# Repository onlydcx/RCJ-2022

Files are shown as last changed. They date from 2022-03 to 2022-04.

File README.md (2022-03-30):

# このプロジェクトについて
ロボカップジュニア2022に出場する機体の全データです。要はオープンソースです。

需要があるかは分かりませんが、公開すること自体が大事だと思うので公開します

# 3Dデータ
3Dデータ フォルダに入ってます。

Autodesk Fusion360で作成しました、f3zファイルなのでFusionでしか開けないと思います。

# ソフトウェア
PlatfomIOで開発しています。

必要なplatformio.iniとmain.cppだけ載せておきます。

質問とかあったらTwitterでDMしてください

# 基板データ
基板データ フォルダに入ってます。
- 「CamBoard」 メイン基板のデータです。OpenMV,Teensyなどが乗ります
- 「FrontLine」 前のLINEセンサーのデータです。ボール補足エリアがあるので前だけラインセンサの形が違います。
- 「Kicker」 キッカー用のMOSFETが乗った回路です。コンデンサは別付けです。
- 「PowerUnit」 リポから5V,3.3Vを生成してメイン基板に送る回路です。ヒューズも乗ります。
- 「SideLine」 横と後ろのラインセンサーのデータです
- 「UI-unit」 UI基盤のデータです。0.96inchのOLEDが乗ります

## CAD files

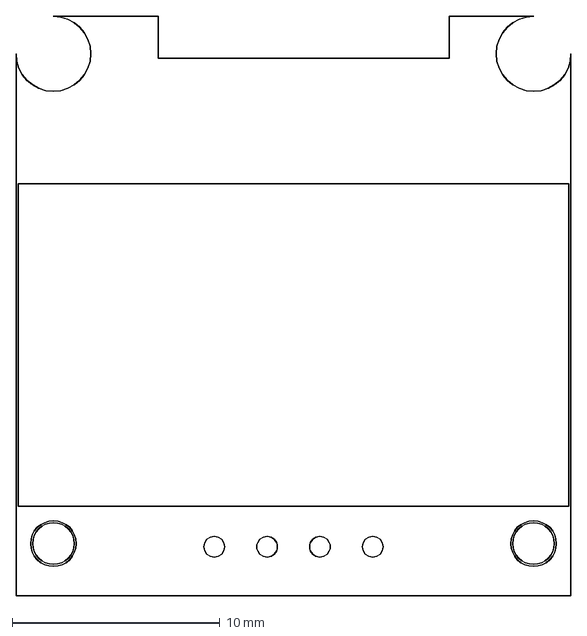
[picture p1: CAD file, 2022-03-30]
基板データ/CamBoard/OLED-Edge.dxf
26.7 x 27.9 mm

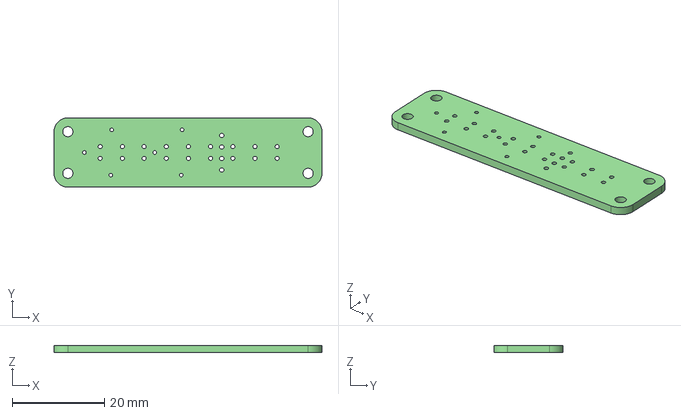
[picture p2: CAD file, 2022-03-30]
基板データ/FrontLine/FrontLine.step
58.0 x 15.0 x 1.60 mm

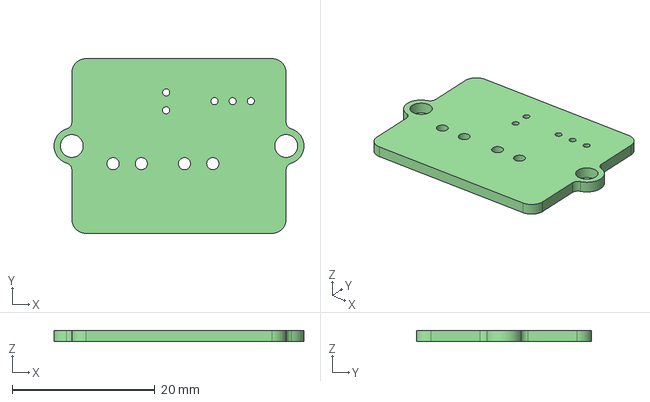
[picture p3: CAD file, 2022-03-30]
基板データ/Kicker/Kicker.step
35.0 x 24.5 x 1.60 mm

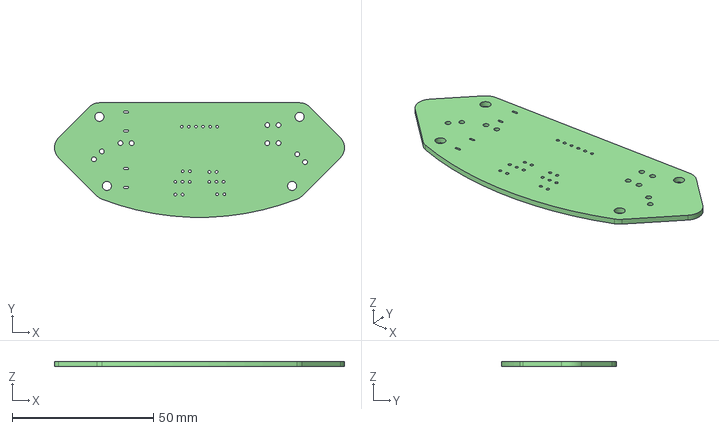
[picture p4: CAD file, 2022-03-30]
基板データ/PowerUnit/PowerUnit.step
102.7 x 40.5 x 1.60 mm

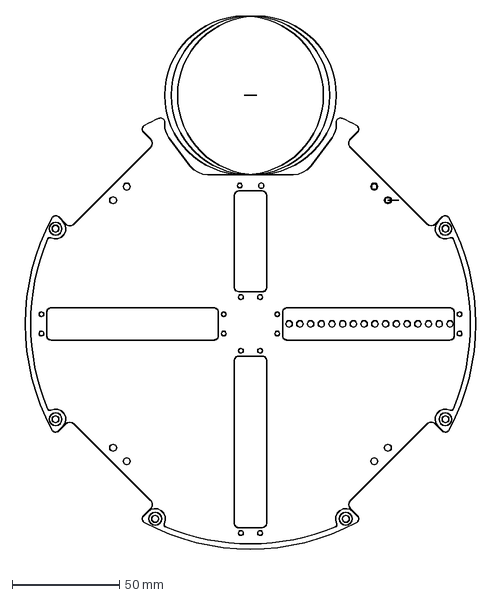
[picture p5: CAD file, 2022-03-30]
基板データ/SideLine/Edge.dxf
218.2 x 252.7 mm

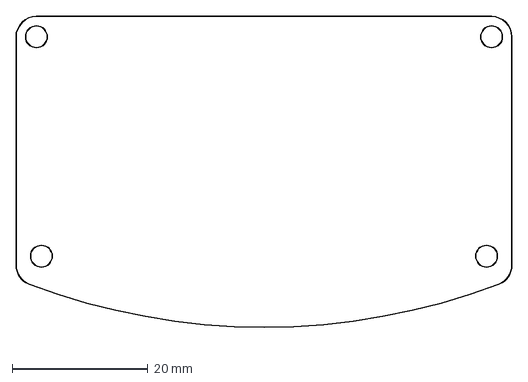
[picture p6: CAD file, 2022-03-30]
基板データ/UI-unit/Edge.dxf
73.0 x 47.9 mm

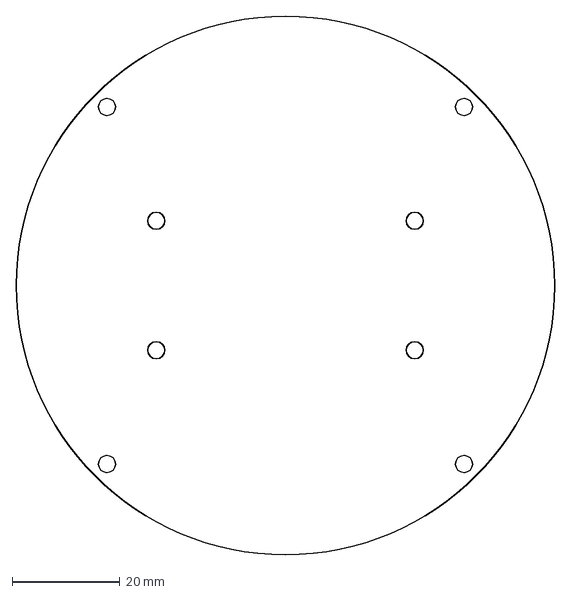
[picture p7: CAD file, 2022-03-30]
基板データ/CamBoard/Edge.dxf
100.0 x 100.0 mm

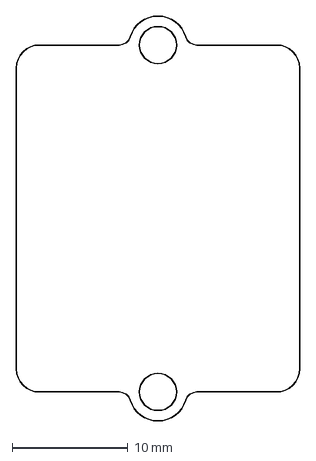
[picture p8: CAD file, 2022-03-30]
基板データ/Kicker/Edge.dxf
24.5 x 35.0 mm

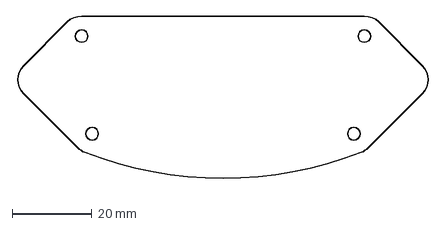
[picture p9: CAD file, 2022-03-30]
基板データ/PowerUnit/Edge.dxf
103.7 x 42.8 mm

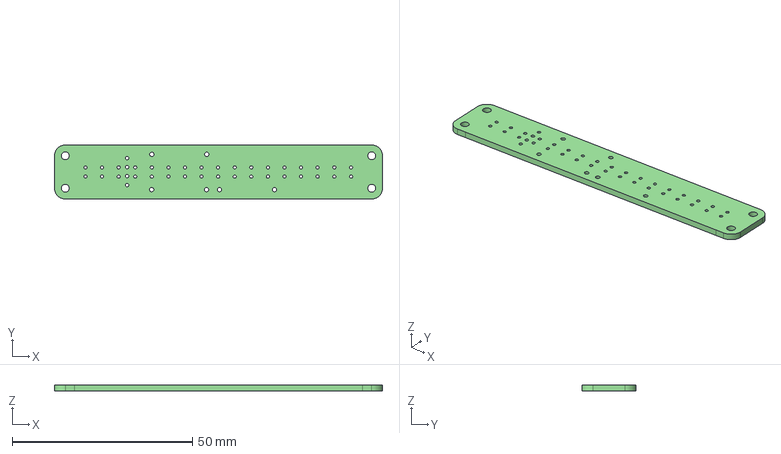
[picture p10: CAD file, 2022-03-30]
基板データ/SideLine/SideLine.step
91.0 x 15.0 x 1.60 mm

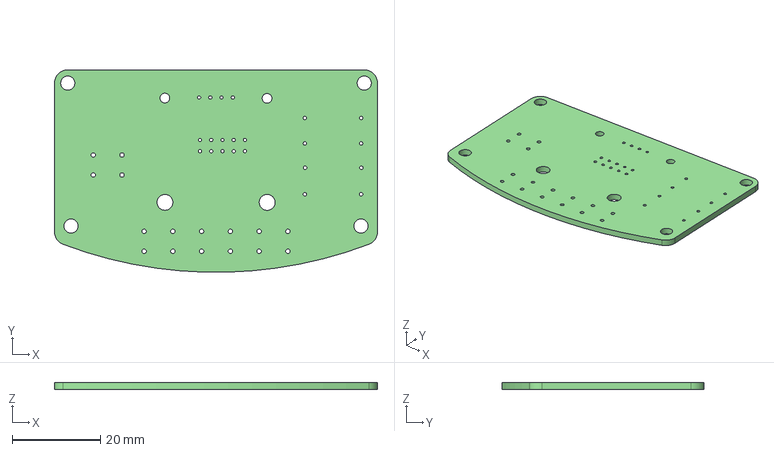
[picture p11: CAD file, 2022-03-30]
基板データ/UI-unit/UI-unit.step
73.0 x 45.7 x 1.60 mm

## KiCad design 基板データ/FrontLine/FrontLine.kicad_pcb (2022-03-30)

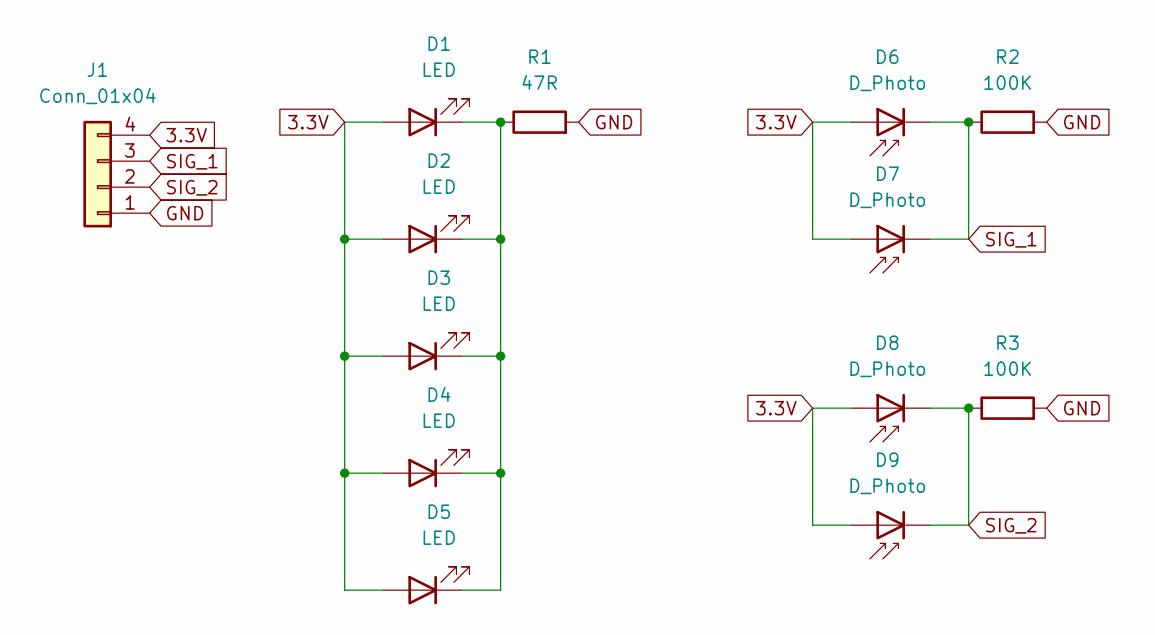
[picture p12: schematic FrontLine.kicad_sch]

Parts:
D1, D2, D3, D4, D5: LED; LED_D3.0mm
D6, D7, D8, D9: D_Photo; NJL7302L_F3
J1: Conn_01x04; JST_XH_S4B-XH-A-1_1x04_P2.50mm_Horizontal
R1: 47R; R_Axial_DIN0309_L9.0mm_D3.2mm_P15.24mm_Horizontal
R2, R3: 100K; R_Axial_DIN0309_L9.0mm_D3.2mm_P15.24mm_Horizontal

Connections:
3.3V: D1.2 (A), D2.2 (A), D3.2 (A), D4.2 (A), D5.2 (A), D6.2 (A), D7.2 (A), D8.2 (A), D9.2 (A), J1.4
GND: J1.1, R1.2, R2.2, R3.2
unnamed: D1.1 (K), D2.1 (K), D3.1 (K), D4.1 (K), D5.1 (K), R1.1
SIG_1: D6.1 (K), D7.1 (K), J1.3, R2.1
SIG_2: D8.1 (K), D9.1 (K), J1.2, R3.1

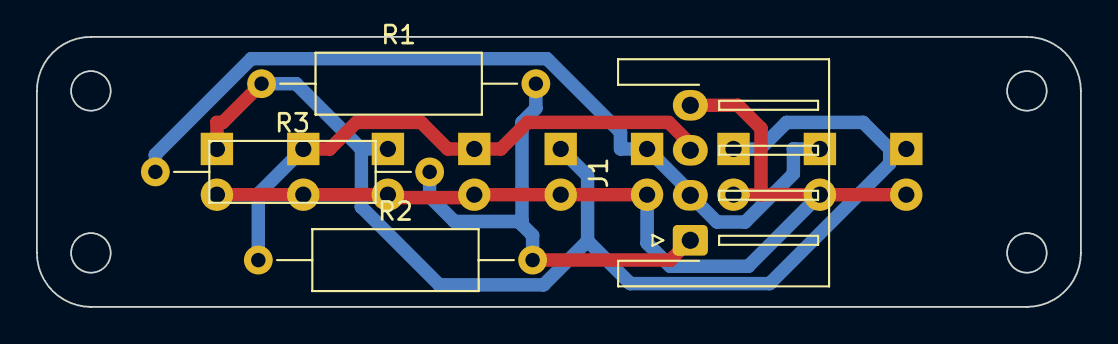
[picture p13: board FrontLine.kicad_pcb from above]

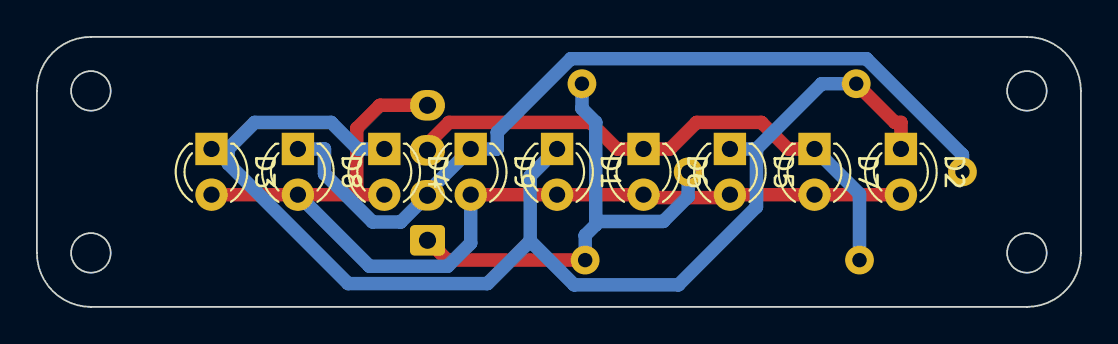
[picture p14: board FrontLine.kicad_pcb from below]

Board: 2 copper layers, 58.0 x 15.0 mm, 13 parts (9 on the bottom side), 5 nets.

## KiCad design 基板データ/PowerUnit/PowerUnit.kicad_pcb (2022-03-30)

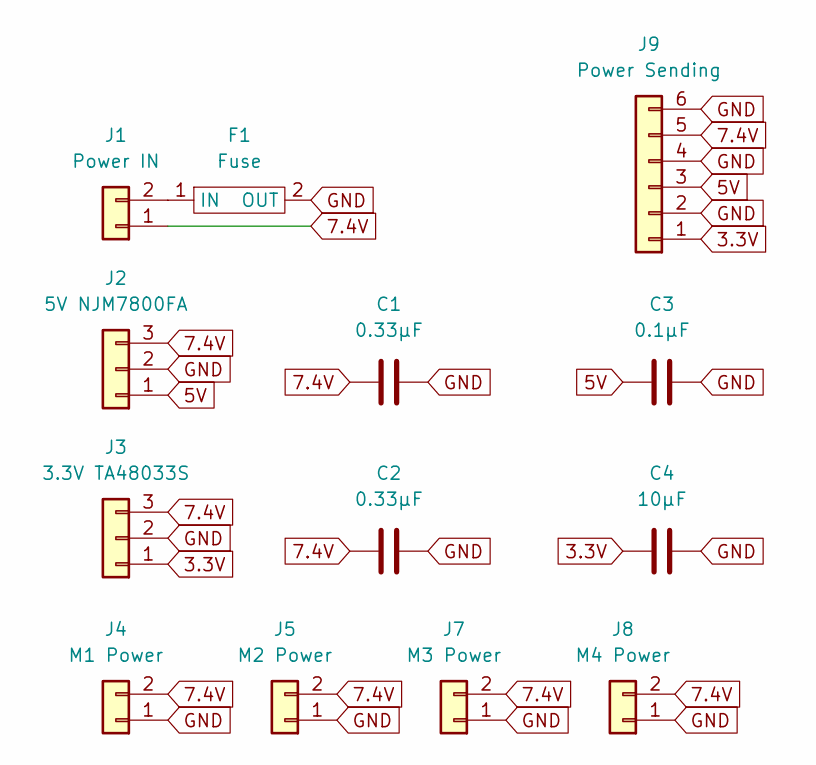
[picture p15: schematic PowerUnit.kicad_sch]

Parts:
C1: 0.33μF; PinSocket_1x02_P2.54mm_Vertical
C2: 0.33µF; PinSocket_1x02_P2.54mm_Vertical
C3: 0.1μF; PinSocket_1x02_P2.54mm_Vertical
C4: 10µF; PinSocket_1x02_P2.54mm_Vertical
F1: Fuse
J1: Power IN; JST_VH_S2P-VH_1x02_P3.96mm_Horizontal
J2: 5V NJM7800FA; PinSocket_1x03_P2.54mm_Horizontal
J3: 3.3V TA48033S; PinSocket_1x03_P2.54mm_Horizontal
J4: M1 Power; JST_VH_S2P-VH_1x02_P3.96mm_Horizontal
J5: M2 Power; JST_VH_S2P-VH_1x02_P3.96mm_Horizontal
J7: M3 Power; JST_VH_S2P-VH_1x02_P3.96mm_Horizontal
J8: M4 Power; JST_VH_S2P-VH_1x02_P3.96mm_Horizontal
J9: Power Sending; JST_XH_S6B-XH-A-1_1x06_P2.50mm_Horizontal

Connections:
3.3V: C4.2, J3.1, J9.1
5V: C3.2, J2.1, J9.3
7.4V: C1.2, C2.2, J1.1, J2.3, J3.3, J4.2, J5.2, J7.2, J8.2, J9.5
GND: C1.1, C2.1, C3.1, C4.1, F1.2 (OUT), J2.2, J3.2, J4.1, J5.1, J7.1, J8.1, J9.2, J9.4, J9.6
unnamed: F1.1 (IN), J1.2

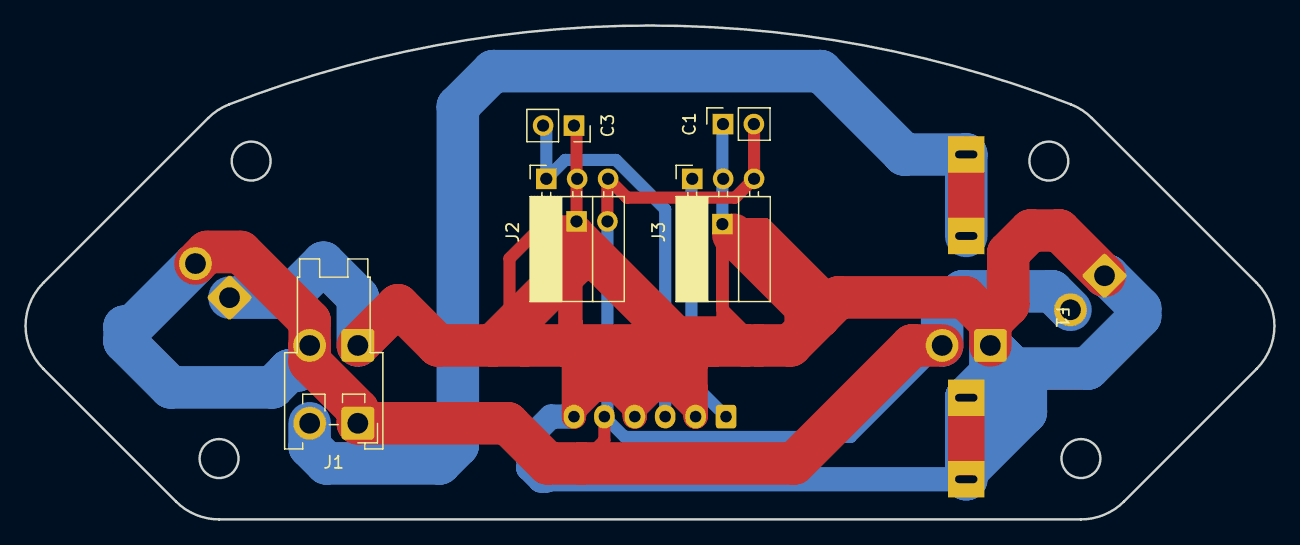
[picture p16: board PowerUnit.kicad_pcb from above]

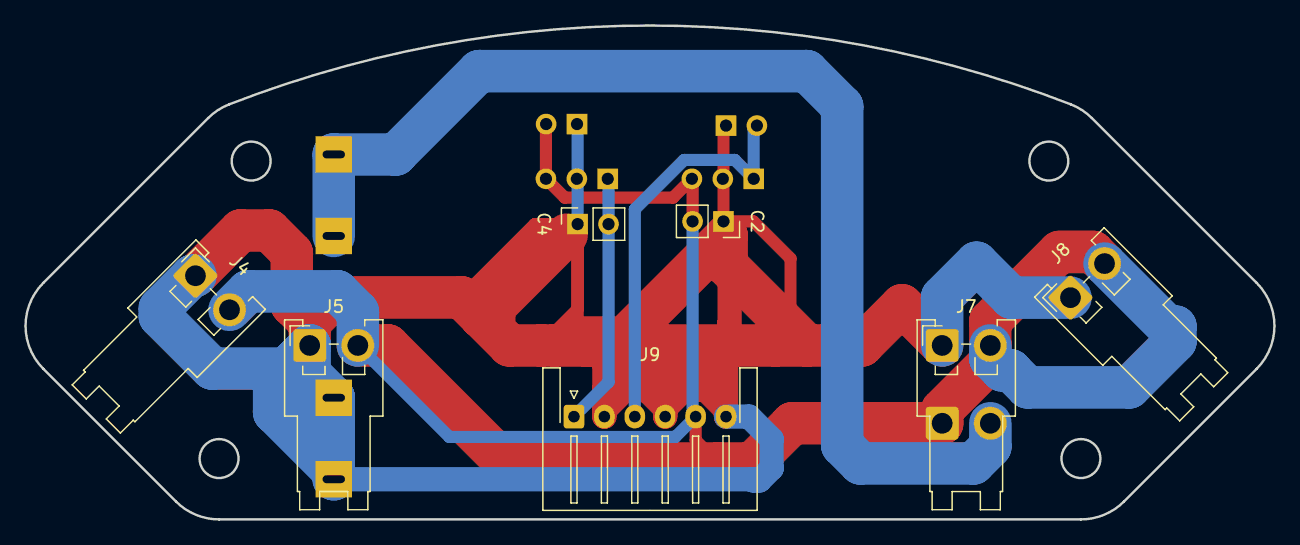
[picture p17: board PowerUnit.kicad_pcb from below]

Board: 2 copper layers, 102.7 x 40.6 mm, 13 parts (7 on the bottom side), 5 nets.

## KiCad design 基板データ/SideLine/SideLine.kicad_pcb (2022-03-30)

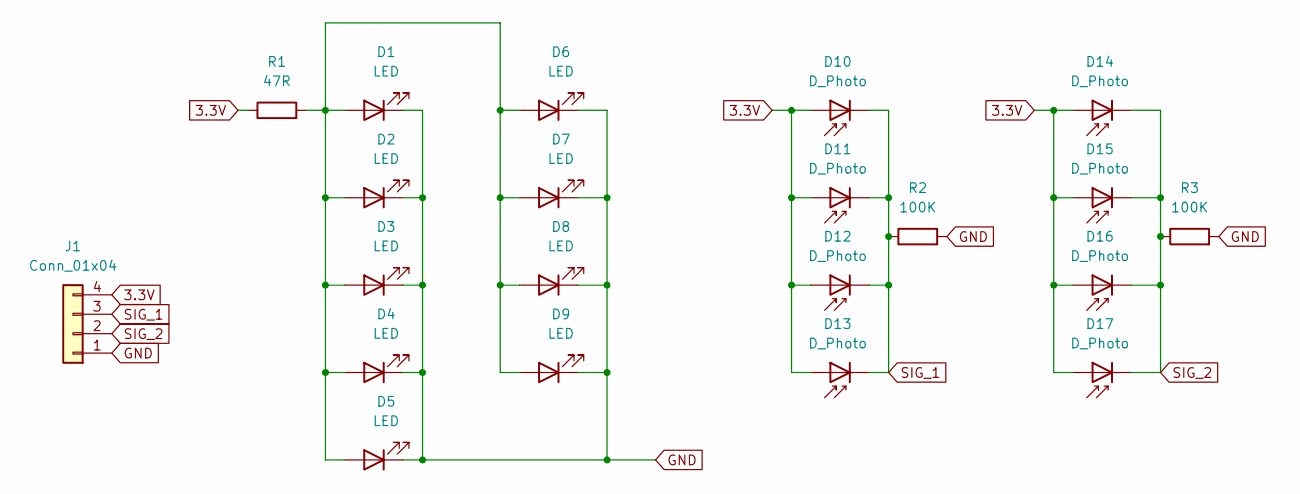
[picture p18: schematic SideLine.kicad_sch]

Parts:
D1, D2, D3, D4, D5, D6, D7, D8, D9: LED; LED_D3.0mm
D10, D11, D12, D13, D14, D15, D16, D17: D_Photo; NJL7302L_F3
J1: Conn_01x04; JST_XH_S4B-XH-A-1_1x04_P2.50mm_Horizontal
R1: 47R; R_Axial_DIN0411_L9.9mm_D3.6mm_P15.24mm_Horizontal
R2, R3: 100K; R_Axial_DIN0411_L9.9mm_D3.6mm_P15.24mm_Horizontal

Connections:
3.3V: D10.2 (A), D11.2 (A), D12.2 (A), D13.2 (A), D14.2 (A), D15.2 (A), D16.2 (A), D17.2 (A), J1.4, R1.1
GND: D1.1 (K), D2.1 (K), D3.1 (K), D4.1 (K), D5.1 (K), D6.1 (K), D7.1 (K), D8.1 (K), D9.1 (K), J1.1, R2.2, R3.2
unnamed: D1.2 (A), D2.2 (A), D3.2 (A), D4.2 (A), D5.2 (A), D6.2 (A), D7.2 (A), D8.2 (A), D9.2 (A), R1.2
SIG_1: D10.1 (K), D11.1 (K), D12.1 (K), D13.1 (K), J1.3, R2.1
SIG_2: D14.1 (K), D15.1 (K), D16.1 (K), D17.1 (K), J1.2, R3.1

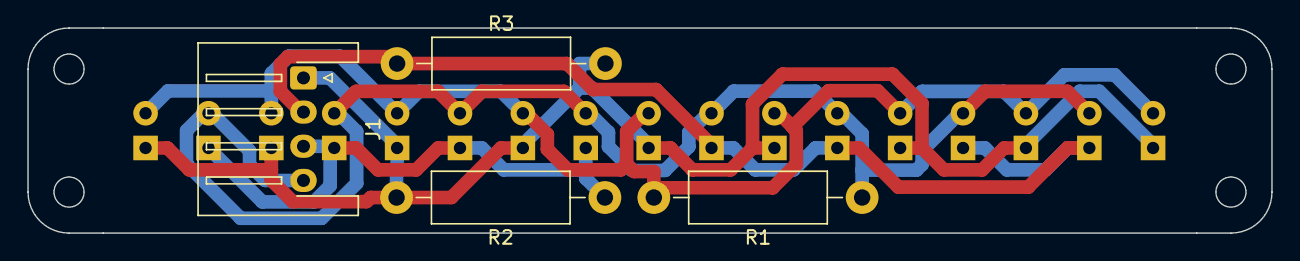
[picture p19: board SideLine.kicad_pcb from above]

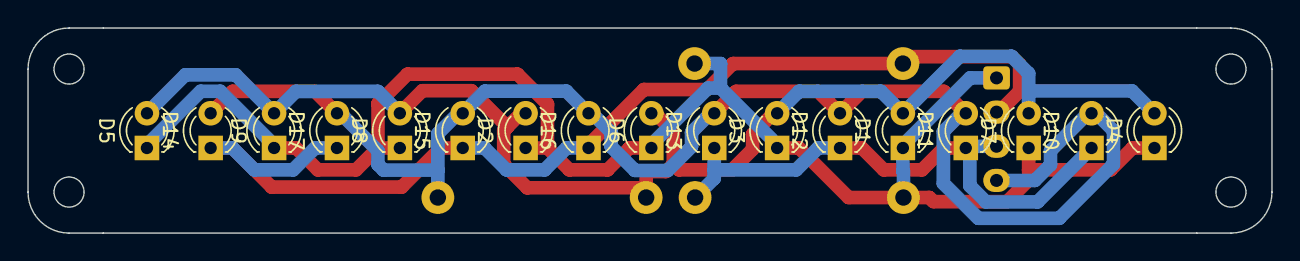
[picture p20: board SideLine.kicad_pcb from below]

Board: 2 copper layers, 91.0 x 15.0 mm, 21 parts (17 on the bottom side), 5 nets.

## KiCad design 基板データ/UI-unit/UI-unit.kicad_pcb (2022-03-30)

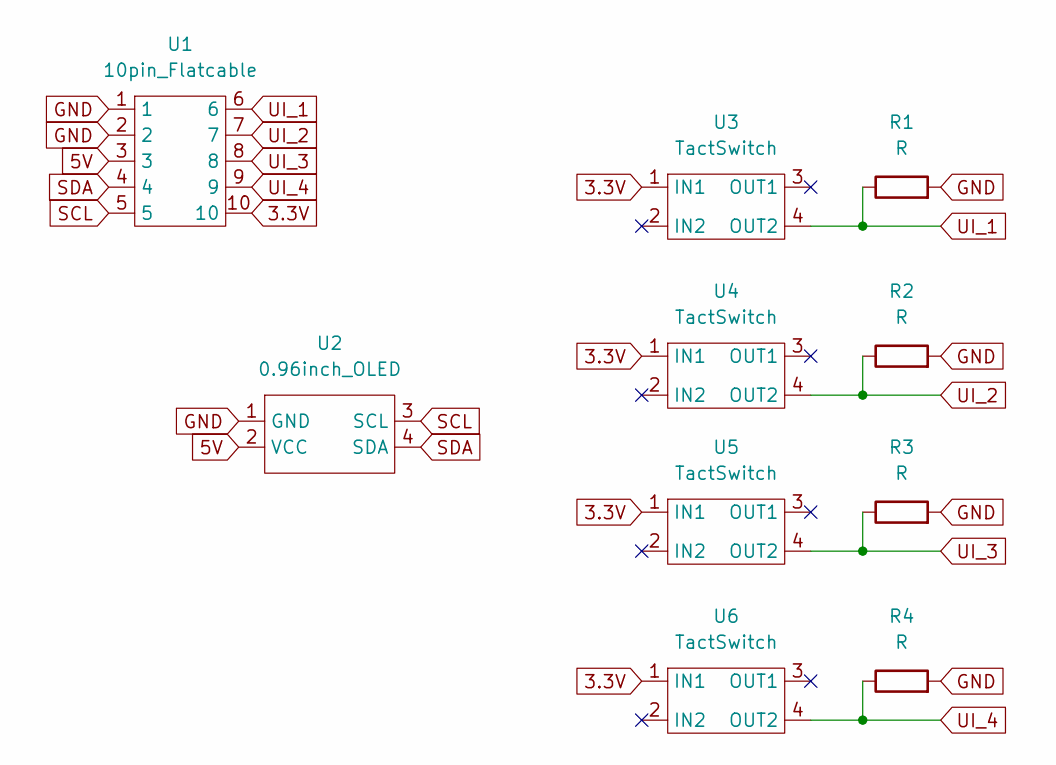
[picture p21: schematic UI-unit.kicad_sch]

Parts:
R1, R2, R3, R4: R; R_Axial_DIN0309_L9.0mm_D3.2mm_P12.70mm_Horizontal
U1: 10pin_Flatcable
U2: 0.96inch_OLED
U3, U4, U5, U6: TactSwitch

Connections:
3.3V: U1.10, U3.1 (IN1), U4.1 (IN1), U5.1 (IN1), U6.1 (IN1)
5V: U1.3, U2.2 (VCC)
GND: R1.2, R2.2, R3.2, R4.2, U1.1, U1.2, U2.1 (GND)
SCL: U1.5, U2.3 (SCL)
SDA: U1.4, U2.4 (SDA)
UI_1: R1.1, U1.6, U3.4 (OUT2)
UI_2: R2.1, U1.7, U4.4 (OUT2)
UI_3: R3.1, U1.8, U5.4 (OUT2)
UI_4: R4.1, U1.9, U6.4 (OUT2)

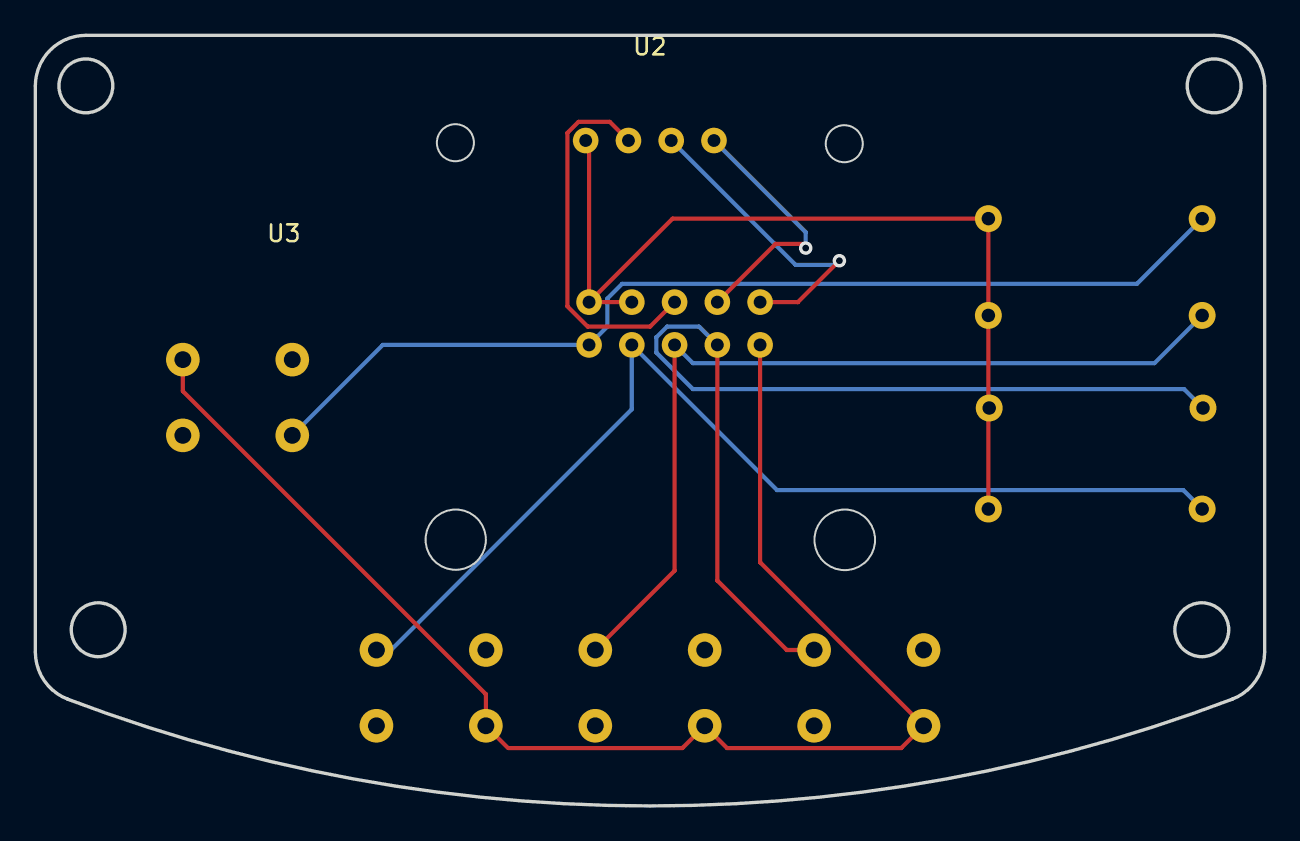
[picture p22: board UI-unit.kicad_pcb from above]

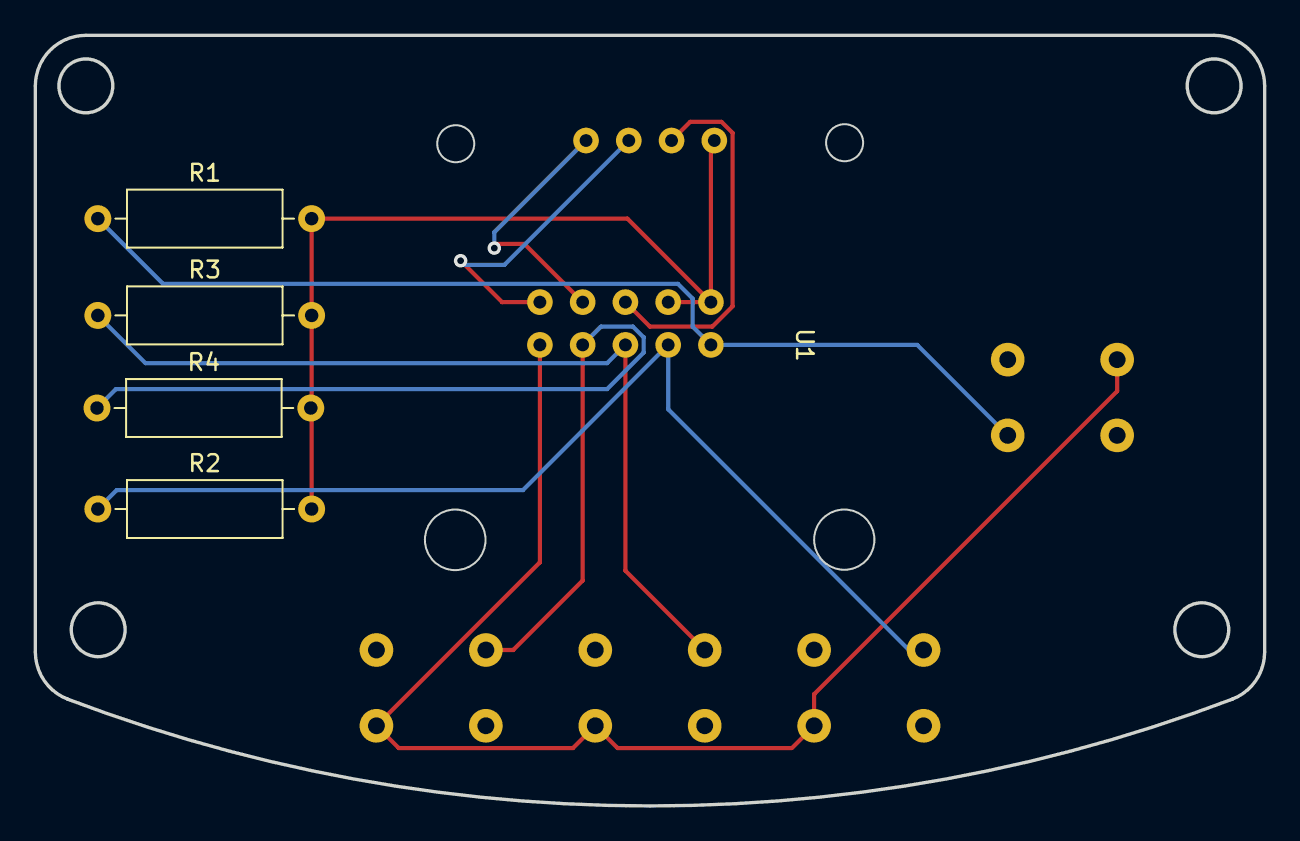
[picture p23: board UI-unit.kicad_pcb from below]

Board: 2 copper layers, 73.0 x 45.8 mm, 10 parts (5 on the bottom side), 9 nets.

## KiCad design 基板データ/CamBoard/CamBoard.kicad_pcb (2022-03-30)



Board: 2 copper layers, 100.0 x 100.0 mm, 28 parts (8 on the bottom side), 39 nets.

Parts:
C1: C; PinSocket_1x02_P2.54mm_Vertical
J1: Power IN; JST_XH_B6B-XH-A_1x06_P2.50mm_Vertical
J2: Voltage; JST_XH_B2B-XH-A_1x02_P2.50mm_Vertical
J3, J5: I2C Port; JST_XH_B4B-XH-A_1x04_P2.50mm_Vertical
J4: Gyro; PinSocket_1x08_P2.54mm_Vertical
J6, J7, J8, J9: HC SR04; PinSocket_1x04_P2.54mm_Vertical
J10: Motor Right; JST_XH_S8B-XH-A_1x08_P2.50mm_Horizontal
J11: Motor Left; JST_XH_S8B-XH-A_1x08_P2.50mm_Horizontal
J12: MotorSwitch; PinSocket_1x03_P2.54mm_Vertical
J13: LIne Right; JST_XH_S8B-XH-A_1x08_P2.50mm_Horizontal
J14: Line Left; JST_XH_S8B-XH-A_1x08_P2.50mm_Horizontal
J15: Conn_01x04; JST_XH_B4B-XH-A_1x04_P2.50mm_Vertical
R1, R2, R5, R6: R; R_Axial_DIN0309_L9.0mm_D3.2mm_P12.70mm_Horizontal
R3, R4: 100K; R_Axial_DIN0309_L9.0mm_D3.2mm_P12.70mm_Horizontal
R7, R9: 100k; R_Axial_DIN0309_L9.0mm_D3.2mm_P12.70mm_Horizontal
R8: 47; R_Axial_DIN0309_L9.0mm_D3.2mm_P12.70mm_Horizontal
U1: 10pin_FlatCable; 20pin_FlatCable
U2: OpenMV; OPENMV_H7
U3: Teensy4.0; Teensy40

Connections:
3.3V: J1.2, J12.3, J13.4, J13.8, J14.4, J14.8, J15.2, R8.2, U1.10
5V: C1.2, J1.4, J3.2, J4.8, J5.2, J6.4, J7.4, J8.4, J9.4, J10.4, J10.8, J11.4, J11.8, U1.3, U2.10, U3.33
7.4V: J1.6, J2.2
A0: J13.1, U3.21
A1: J13.2, U3.22
A2: J13.5, U3.23
A3: J13.6, U3.24
A6: J14.1, U3.27
A7: J14.2, U3.28
A8: J14.5, U3.29
A9: J14.6, U3.30
A12: J15.1, R9.2, U3.37
GND: C1.1, J1.1, J1.3, J1.5, J2.1, J3.1, J4.7, J5.1, J6.1, J7.1, J8.1, J9.1, J10.3, J10.7, J11.3, J11.7, J13.3, J13.7, J14.3, J14.7, J15.3, R3.1, R4.1, R7.1, R9.1, U1.1, U1.2, U2.9, U3.1, U3.17, U3.32
HC-SR04-Back: J8.3, R5.2
HC-SR04-Front: J6.3, R1.2
HC-SR04-Left: J7.3, R2.2
HC-SR04-Right: J9.3, R6.2
LED1: R4.2, U3.42
LED2: R3.2, U3.41
M1_DIR: J10.2, U3.5
M1_PWM: J10.1, U3.4
M2_DIR: J10.6, U3.7
M2_PWM: J10.5, U3.6
M3_DIR: J11.2, U3.9
M3_PWM: J11.1, U3.8
M4_DIR: J11.6, U3.11
M4_PWM: J11.5, U3.10
unnamed: J6.2, R1.1
unnamed: J7.2, R2.1
unnamed: J8.2, R5.1
unnamed: J9.2, R6.1
unnamed: J12.2, R7.2, U3.43
unnamed: J15.4, R8.1
RX: U2.3, U3.39
SCL: J3.4, J4.6, J5.4, U1.5, U3.26
SDA: J3.3, J4.5, J5.3, U1.4, U3.25
TX: U2.4, U3.40
UI_3: U1.8, U3.44
UI_4: U1.9, U3.38

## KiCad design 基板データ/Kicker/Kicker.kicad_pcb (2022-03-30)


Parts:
J1: signal in; JST_XH_S2B-XH-A_1x02_P2.50mm_Horizontal
J2: OUT; JST_VH_B2PS-VH_1x02_P3.96mm_Horizontal
J3: IN; JST_VH_B2PS-VH_1x02_P3.96mm_Horizontal
J4: 2SK703; PinSocket_1x03_P2.54mm_Vertical

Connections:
35V: J2.2, J3.2
GND: J1.2, J3.1, J4.3
OUT-: J2.1, J4.2
SIG: J1.1, J4.1


Board: 2 copper layers, 35.0 x 24.5 mm, 4 parts (0 on the bottom side), 4 nets.

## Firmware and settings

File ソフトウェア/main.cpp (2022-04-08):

#include "Arduino.h"
#include <Wire.h>
#include <Adafruit_GFX.h>
#include <Adafruit_SSD1306.h>
#include <MPU6050_6Axis_MotionApps20.h>
#include <CytronMotorDriver.h>

#define LeftPin 33
#define RightPin 27

#define OpenMV Serial7


#define SCREEN_WIDTH 128
#define SCREEN_HEIGHT 64

#define SIZE_OF_ARRAY(array) (sizeof(array) / sizeof(array[0]))

#define OLED_RESET 4
#define SCREEN_ADDRESS 0x3C

#define w display.width()
#define h display.height()

#define LeftPush isPush(30)
#define CenterPush isPush(33)
#define OnOffPush isPush(31)
#define RightPush isPush(27)
#define AnyPush (LeftPush || CenterPush || OnOffPush || RightPush)

#define isOnFront (isOnLine(1,0) || isOnLine(1,1)) // 前 (中,外)
#define isOnRight (isOnLine(0,0) || isOnLine(0,1)) // 右 (外,中)
#define isOnBack (isOnLine(2,0) || isOnLine(2,1)) // 後 (外,中)
#define isOnLeft (isOnLine(3,0) || isOnLine(3,1)) // 左 (外,中)

#define isOutFront isOnLine(1,1)
#define isOutRight isOnLine(0,0)
#define isOutBack isOnLine(2,0)
#define isOutLeft isOnLine(3,0)

#define isInFront isOnLine(1,0)
#define isInRight isOnLine(0,1)
#define isInBack isOnLine(2,1)
#define isInLeft isOnLine(3,1)

#define isOnOut (isOnLine(1,1) || isOnLine(0,0) || isOnLine(2,0) || isOnLine(3,0))
#define isOnIn (isOnLine(1,0) || isOnLine(0,1) || isOnLine(2,1) || isOnLine(3,1))

#define isOnAny (isOnOut || isOnIn)

CytronMD motor1(PWM_DIR, 5, 4);
CytronMD motor2(PWM_DIR, 3, 2);
CytronMD motor3(PWM_DIR, 9, 8);
CytronMD motor4(PWM_DIR, 7, 6);

Adafruit_SSD1306 display(SCREEN_WIDTH, SCREEN_HEIGHT, &Wire, OLED_RESET);

MPU6050 mpu;
static uint8_t mpuIntStatus;
static bool dmpReady = false;
static uint16_t packetSize;
int16_t Gyro_Now = 0, Gyro = 0, Gyro_Offset = 0;
uint16_t fifoCount;
uint8_t fifoBuffer[64];
Quaternion q;
VectorFloat gravity;
float ypr[3];
int Gyro_X, Gyro_Y, Gyro_Z, Accel_Z;

int speed = 150;
bool isFirstSetSpeed = true;

int ave_motor_power[4][10] = {0};
int ave_mpPlus = 0;

int prevIR, dirPlus, cnt;
int dirIR = 0;

int getCam() {
   int re = 0;
   if (OpenMV.available()) {
      int a = OpenMV.read();
      if (a >= 0 && a <= 70) {
         re = a;
      }
      else {
         re = 0;
      }
   }
   return re;
}

int getDx(String txt) {
   int char_len = txt.length();
   return (display.width() / 2) - ((char_len / 2) * 11);
}

int GyroGet(void) {
   mpuIntStatus = false;
   mpuIntStatus = mpu.getIntStatus();
   fifoCount = mpu.getFIFOCount();

   if ((mpuIntStatus & 0x10) || fifoCount == 1024) {
      mpu.resetFIFO();
   }
   else if (mpuIntStatus & 0x02) {
      while (fifoCount < packetSize) {
         fifoCount = mpu.getFIFOCount();
      }
      mpu.getFIFOBytes(fifoBuffer, packetSize);
      fifoCount -= packetSize;
      mpu.dmpGetQuaternion(&q, fifoBuffer);
      mpu.dmpGetGravity(&gravity, &q);
      mpu.dmpGetYawPitchRoll(ypr, &q, &gravity);
      Gyro_Now = degrees(ypr[0]) + 180;
      Gyro = Gyro_Now + Gyro_Offset - 180;
      if (Gyro < 0) {
         Gyro += 360;
      }
      if (Gyro > 359) {
         Gyro -= 360;
      }
   }
   return Gyro;
}

void Gryo_init() {
   mpu.initialize();
   if (mpu.testConnection() != true) {
      Serial.println("MPU disconection");
   }
   if (mpu.dmpInitialize() != 0) {
      Serial.println("MPU break");
   }
   mpu.setXGyroOffset(Gyro_X);
   mpu.setYGyroOffset(Gyro_Y);
   mpu.setZGyroOffset(Gyro_Z);
   mpu.setZAccelOffset(Accel_Z);
   mpu.setDMPEnabled(true);
   mpuIntStatus = mpu.getIntStatus();
   dmpReady = true;
   packetSize = mpu.dmpGetFIFOPacketSize();
}

void selectGyro(int number) {
   switch (number) {
      case 0:
         Gyro_X = -93, Gyro_Y = 77, Gyro_Z = 10, Accel_Z = 1561;
         break;
      case 1:
         Gyro_X = 114, Gyro_Y = 61, Gyro_Z = 95, Accel_Z = 1719;
         break;
      case 2:
         Gyro_X = -118, Gyro_Y = 22, Gyro_Z = -61, Accel_Z = 797;
         break;
      case 3:
         Gyro_X = -364, Gyro_Y = -29, Gyro_Z = 9, Accel_Z = 1846;
         break;
      case 4:
         Gyro_X = 50, Gyro_Y = 22, Gyro_Z = 12, Accel_Z = 1347;
         break;
      default:
         Serial.println("error in selectGyro()");
         Gyro_X = 0, Gyro_Y = 0, Gyro_Z = 0, Accel_Z = 0;
         break;
   }
}

int getVah(int f) {
   byte val = 0;
   Wire.beginTransmission(0x0E);
   Wire.write(f);
   Wire.endTransmission();
   // Wire.endTransmission(false); // falseの方が良いらしい...?
   Wire.requestFrom(0x0E, 1);
   while (Wire.available()) {
      val = Wire.read();
   }
   return (int)val;
}

int IRval(int i) {
   int a = getVah(0x04);
   int b = getVah(0x05);
   int c = getVah(0x06);
   int d = getVah(0x07);
   int re_angle;
   int re_strength;

   if (d < 10) {
      re_angle = a;
      re_strength = b;
   }
   else {
      re_angle = c;
      re_strength = d;
   }

   if(i != 1) {
      return re_strength;
   }
   else {
      return re_angle*5;
   }
}

bool isPush(int num) {
   if (digitalRead(num)) {
      while (digitalRead(num)) {
         if (!digitalRead(num)) {
            break;
         }
      }
      return 1;
   }
   else {
      return 0;
   }
}

void display_init() {
   if (!display.begin(SSD1306_SWITCHCAPVCC, SCREEN_ADDRESS)) {
      Serial.println(F("SSD1306 allocation failed"));
      // for (;;) ;
   }
}

void printKick() {
   String txt = "Kick Test";
   int char_len = txt.length();
   int drawX = (display.width() / 2) - ((char_len / 2) * 13);
   display.clearDisplay();
   display.setTextSize(2);
   display.setTextColor(SSD1306_WHITE);
   display.setCursor(drawX, 20);
   display.println(txt);
   display.display();
}

void printIR() {
   int cx = w / 4, cy = h / 2, r = 18;
   float deg = IRval(1), Rad;
   display.clearDisplay();
   Rad = (deg - 90) / (180 / PI);
   display.drawCircle(cx, cy, w / 12, SSD1306_WHITE);
   display.drawCircle(cx, cy, w / 5, SSD1306_WHITE);
   display.fillCircle(cx + r * cos(Rad), cy + r * sin(Rad), 3, 1);
   display.drawLine(cx, 0, cx, h, SSD1306_WHITE);
   display.drawLine(0, cy, cx * 2, cy, SSD1306_WHITE);
   display.setTextSize(2);
   display.setTextColor(SSD1306_WHITE);
   display.setCursor(w / 2 + 10, 10);
   display.println("Ball");
   display.setTextSize(2);
   display.setTextColor(SSD1306_WHITE);
   display.setCursor(w / 2 + 10, h / 2 + 5);
   display.println((int)deg);
   display.display();
}

int analogPins[4][2] = {
   {0, 1}, {2, 3}, {6, 7}, {8, 9}
};

int thresholds[4][2] = {
   {1023, 1023},
   {1023, 1023},
   {1023, 1023},
   {1023, 1023}
};

int LineMin[4][2] = {1023};
int LineMax[4][2] = {0};

void LineThUpdate() {
   String txt = "Update";
   display.clearDisplay();
   display.setTextSize(2);
   display.setTextColor(SSD1306_WHITE);
   display.setCursor(getDx(txt), 30);
   display.println(txt);
   display.display();
   if(OnOffPush) {
      txt = "Updating";
      display.clearDisplay();
      display.setTextSize(2);
      display.setTextColor(SSD1306_WHITE);
      display.setCursor(getDx(txt), 30);
      display.println(txt);
      display.display();
      while(!OnOffPush) {
         for(int i = 0; i < 4; i++) {
            for(int j = 0; j < 2; j++) {
               int val = analogRead(analogPins[i][j]);
               if(val < LineMin[i][j]) {
                  LineMin[i][j] = val;
               }
               if(val > LineMax[i][j]) {
                  LineMax[i][j] = val;
               }
            }
         }
      }
      for(int i = 0; i < 4; i++) {
         for(int j = 0; j < 2; j++) {
            int border = 2;
            int add = -50;
            int diff = abs(LineMax[i][j] - LineMin[i][j]);
            int threshold = LineMax[i][j] - (diff / border);
            thresholds[i][j] = threshold + add;
         }
      }
      txt = "done";
      display.clearDisplay();
      display.setTextSize(2);
      display.setTextColor(SSD1306_WHITE);
      display.setCursor(getDx(txt), 30);
      display.println(txt);
      display.display();
      delay(500);
   }
}

int getLine(int i, int j) {
   return analogRead(analogPins[i][j]);
}

bool isOnLine(int i, int j) {
   return (analogRead(analogPins[i][j]) > thresholds[i][j])? true: false;
}

void printLine() {
   int cx = w/4, cy = h/2;
   display.clearDisplay();
   int paddingC = 10, paddingI = 3;
   int r = w / 5;
   display.drawCircle(cx, cy, r, SSD1306_WHITE);
   display.drawLine(cx, paddingC, cx, cy - paddingI, SSD1306_WHITE);
   display.drawLine(cx, cy + paddingI, cx, h - paddingC, SSD1306_WHITE);
   display.drawLine(paddingC, cy, cx - paddingI, cy, SSD1306_WHITE);
   display.drawLine(cx + paddingI, cy, cx * 2 - paddingC, cy, SSD1306_WHITE);
   String isOnTXT = "";
   if(isOnFront) {
      display.fillRect(cx-2, 10, 5, r-5, SSD1306_WHITE);
      isOnTXT += "F";
   }
   if(isOnRight) {
      display.fillRect(cx+3, cy-2, r-5, 5, SSD1306_WHITE);
      isOnTXT += "R";
   }
   if(isOnBack) {
      display.fillRect(cx-2, cy+3, 5, r-5, SSD1306_WHITE);
      isOnTXT += "B";
   }
   if(isOnLeft) {
      display.fillRect(10, cy-2, r-5, 5, SSD1306_WHITE);
      isOnTXT += "L";
   }
   display.setTextColor(SSD1306_WHITE);
   display.setTextSize(2);
   display.setCursor(w/2 + 10, 10);
   display.println("Line");
   display.setTextSize(2);
   display.setTextColor(SSD1306_WHITE);
   display.setCursor(w / 2 + 10, h / 2 + 5);
   display.println(isOnTXT);
   display.display();
}

int speed_status = 0;
bool speed_isPushed = false;

String speed_mode[] = {"0", "10", "50", "100", "150", "170", "200", "220", "250"};
int speed_mode_len = SIZE_OF_ARRAY(speed_mode);

void changeSpeed() {
   if (LeftPush) {
      speed_isPushed = true;
      if ((speed_status <= speed_mode_len - 1) && (speed_status >= 1)) {
         speed_status--;
      }
   }
   if (RightPush) {
      speed_isPushed = true;
      if ((speed_status <= speed_mode_len - 2) && (speed_status >= 0)) {
         speed_status++;
      }
   }
   if (speed_isPushed) {
      display.clearDisplay();
      if (speed_status <= speed_mode_len - 2) {
         display.drawTriangle(90, 45, 90, 55, 100, 50, SSD1306_WHITE);
      }
      if (speed_status >= 1) {
         display.drawTriangle(34, 45, 34, 55, 24, 50, SSD1306_WHITE);
      }
      int char_len = speed_mode[speed_status].length();
      int drawX = (display.width() / 2) - ((char_len / 2) * 11);
      display.setTextSize(2);
      display.setTextColor(SSD1306_WHITE);
      display.setCursor(drawX, 7);
      display.println(speed_mode[speed_status]);
      display.drawLine(0, 32, 128, 32, SSD1306_WHITE);
      display.display();
      speed = atoi((speed_mode[speed_status]).c_str());
   }
}

void printIMU() {
   int cx = w / 4, cy = h / 2, r = 21;
   float deg = GyroGet(), Rad;
   display.clearDisplay();
   Rad = (deg - 90) / (180 / PI);
   display.drawCircle(cx, cy, w / 6, SSD1306_WHITE);
   display.fillCircle(cx + r * cos(Rad), cy + r * sin(Rad), 3, 1);
   display.drawLine(cx, 0, cx, h, SSD1306_WHITE);
   display.drawLine(0, cy, cx * 2, cy, SSD1306_WHITE);
   display.setTextSize(2);
   display.setTextColor(SSD1306_WHITE);
   display.setCursor(w / 2 + 10, 10);
   display.println("Gyro");
   display.setTextSize(2);
   display.setTextColor(SSD1306_WHITE);
   display.setCursor(w / 2 + 10, h / 2 + 5);
   display.println((int)deg);
   display.display();
}

void RST_Gy() {
   String txt = "RST Gyro";
   int char_len = txt.length();
   int drawX = (display.width() / 2) - ((char_len / 2) * 11);
   display.clearDisplay();
   display.setTextSize(2);
   display.setTextColor(SSD1306_WHITE);
   display.setCursor(drawX, 30);
   display.println(txt);
   display.display();
   if(OnOffPush) {
      String txt = "Reseting";
      int char_len = txt.length();
      int drawX = (display.width() / 2) - ((char_len / 2) * 11);
      display.clearDisplay();
      display.setTextSize(2);
      display.setTextColor(SSD1306_WHITE);
      display.setCursor(drawX, 30);
      display.println(txt);
      display.display();
      Gryo_init();
      delay(100);
   }
}

void motorStop() {
   motor1.setSpeed(0);
   motor2.setSpeed(0);
   motor3.setSpeed(0);
   motor4.setSpeed(0);
}

void motor(int angle) {

   double motor_power[4];
   double max_power; // ????

   motor_power[0] = cos((45 - angle) / 180.0 * PI);
   motor_power[1] = cos((135 - angle) / 180.0 * PI);
   motor_power[2] = cos((-45 - angle) / 180.0 * PI);
   motor_power[3] = cos((-135 - angle) / 180.0 * PI);

   for (int i = 0; i < 4; i++) {
      if (abs(motor_power[i]) > max_power) {
         max_power = abs(motor_power[i]);
      }
   }

   for (int i = 0; i < 4; i++) {
      motor_power[i] = speed * motor_power[i] / max_power;
      for (int j = 9; j > 0; j--) {
         ave_motor_power[i][j] = ave_motor_power[i][j - 1];
      }
      ave_motor_power[i][0] = motor_power[i];
      ave_mpPlus = 0;
      for (int k = 0; k < 10; k++) {
         ave_mpPlus = ave_mpPlus + ave_motor_power[i][k];
      }
      motor_power[i] = ave_mpPlus / 10;
   }
   motor1.setSpeed(-motor_power[1]);
   motor2.setSpeed(motor_power[0]);
   motor3.setSpeed(motor_power[2]);
   motor4.setSpeed(motor_power[3]);
}

void lightMotor(int angle) {
   double motor_power[4];
   double max_power; // ????

   motor_power[0] = cos((45 - angle) / 180.0 * PI);
   motor_power[1] = cos((135 - angle) / 180.0 * PI);
   motor_power[2] = cos((-45 - angle) / 180.0 * PI);
   motor_power[3] = cos((-135 - angle) / 180.0 * PI);

   for (int i = 0; i < 4; i++) {
      if (abs(motor_power[i]) > max_power) {
         max_power = abs(motor_power[i]);
      }
   }

   for (int i = 0; i < 4; i++) {
      motor_power[i] = speed * motor_power[i] / max_power;
   }

   motor1.setSpeed(-motor_power[1]);
   motor2.setSpeed(motor_power[0]);
   motor3.setSpeed(motor_power[2]);
   motor4.setSpeed(motor_power[3]);
}

void kick() {
   digitalWrite(10, HIGH);
   delay(100);
   digitalWrite(10, LOW);
   delay(100);
}

void followBall() {
   int diff = 10;
   int S = 50;
   int MAX = 150;
   int GY = GyroGet();
   if(GY >= diff && GY < 90) {
      motor1.setSpeed(S);
      motor2.setSpeed(S);
      motor3.setSpeed(-S);
      motor4.setSpeed(S);
   }
   else if(GY >= 90 && GY < 180) {
      motor1.setSpeed(MAX);
      motor2.setSpeed(MAX);
      motor3.setSpeed(-MAX);
      motor4.setSpeed(MAX);
   }
   else if(GY >= 180 && GY < 275) {
      motor1.setSpeed(-MAX);
      motor2.setSpeed(-MAX);
      motor3.setSpeed(MAX);
      motor4.setSpeed(-MAX);
   }
   else if(GY >= 275 && GY < 360 - diff) {
      motor1.setSpeed(-S);
      motor2.setSpeed(-S);
      motor3.setSpeed(S);
      motor4.setSpeed(-S);
   }
   else {
      int dlTime = 300;
      if(isOnFront) {
         motorStop();
         delay(100);
         lightMotor(180);
         delay(dlTime);
      }
      if(isOnRight) {
         motorStop();
         delay(100);
         lightMotor(270);
         delay(dlTime);
      }
      if(isOnBack) {
         motorStop();
         delay(100);
         lightMotor(0);
         delay(dlTime);
      }      
      if(isOnLeft) {
         motorStop();
         delay(100);
         lightMotor(90);
         delay(dlTime);
      }
      else {
         dirIR = IRval(1);
         if (abs(prevIR - dirIR) > 30) {
            cnt++;
            if (cnt == 5) {
               cnt = 0;
               prevIR = dirIR;
            }
            else {
               dirIR = prevIR;
            }
         }
         else {
            cnt = 0;
            prevIR = dirIR;
         }

         int IR = dirIR;
         if(IR == 0 || IR == 5 || IR == 355) {
            motor(0);
         }
         else if (IR <= 10 || IR >= 350){
            motor(IR);
         }
         else {
            if (IR <= 180){
               motor(IR + 50);
            }
            else {
               motor(IR - 50);
            }
         }
      }
   }
}
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
void loop() {
   if (LeftPush) {
      isPushed = true;
      if ((status <= mode_len - 1) && (status >= 1)) {
         status--;
      }
   }
   if (RightPush) {
      isPushed = true;
      if ((status <= mode_len - 2) && (status >= 0)) {
         status++;
      }
   }
   if (CenterPush) {
      switch (status) {
         case 0:
            display.clearDisplay();
            display.display();
            while(!CenterPush) {
               followBall2();
            }
            motorStop();
            break;
         case 1:
            while (!CenterPush) {
               printIR();
            }
            break;
         case 2:
            while (!CenterPush) {
               printIMU();
            }
            break;
         case 3:
            while (!CenterPush) {
               printKick();
               if (digitalRead(31)) {
                  kick();
               }
            }
            break;
         case 4:
            if (isFirstSetSpeed) {
               int char_len = ((String)speed).length();
               int drawX = (display.width() / 2) - ((char_len / 2) * 11);
               display.clearDisplay();
               display.setTextSize(2);
               display.setTextColor(SSD1306_WHITE);
               display.setCursor(drawX, 7);
               display.println(speed);
               display.drawLine(0, 32, 128, 32, SSD1306_WHITE);
               if (atoi((speed_mode[0]).c_str()) < speed) {
                  display.drawTriangle(90, 45, 90, 55, 100, 50, SSD1306_WHITE);
               }
               if (atoi((speed_mode[speed_mode_len - 1]).c_str()) > speed) {
                  display.drawTriangle(34, 45, 34, 55, 24, 50, SSD1306_WHITE);
               }
               for (int i = 0; i < speed_mode_len; i++) {
                  if (atoi((speed_mode[i]).c_str()) == speed) {
                     speed_status = i + 1;
                     break;
                  }
                  if (atoi((speed_mode[i]).c_str()) > speed) {
                     speed_status = i;
                     break;
                  }
               }
               speed = atoi((speed_mode[speed_status]).c_str());
               display.display();
               isFirstSetSpeed = !isFirstSetSpeed;
            }
            while (!CenterPush) {
               changeSpeed();
            }
            break;
         case 5:
            while (!CenterPush) {
               RST_Gy();
            }
            break;
         case 6:
            while (!CenterPush) {
               printLine();
            }
            break;
         case 7:
            while (!CenterPush) {
               LineThUpdate();
            }
            break;
         default:
            break;
      }
   }
   if (isPushed) {
      int char_len = mode[status].length();
      int drawX = (display.width() / 2) - ((char_len / 2) * 12);
      display.clearDisplay();
      display.setTextSize(2);
      display.setTextColor(SSD1306_WHITE);
      display.setCursor(drawX, 7);
      display.println(mode[status]);
      display.drawLine(0, 32, 128, 32, SSD1306_WHITE);
      if (status <= mode_len - 2) {
         display.drawTriangle(90, 45, 90, 55, 100, 50, SSD1306_WHITE);
      }
      if (status >= 1) {
         display.drawTriangle(34, 45, 34, 55, 24, 50, SSD1306_WHITE);
      }
      display.display();
   }
}

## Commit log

2022-03-30 基板データを更新
    [CamBoard.dsn, CamBoard.kicad_pcb, CamBoard.kicad_sch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]
2022-03-30 3Dデータを追加
2022-03-30 ソースコードを追加
2022-03-30 説明を追加
2022-04-08 ラインセンサの動きを調整 & キッカー関数を改良(未動作)
    ラインセンサ・・・白線検出時、一定時間白線方向に向かわないように改良
    キッカー・・・他の動作に影響が出ないようにmillsを使って書き直し(動作未確認)
    モーター・・・動きながら常に0度を向くように調整
2022-04-08 OpenMV.pyを作成
